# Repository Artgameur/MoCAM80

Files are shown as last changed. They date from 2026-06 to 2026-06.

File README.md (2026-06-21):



<p align="center">
  

  <a href="README.fr.md">
    
  </a>
</p>

# Table of Contents

* [Introduction](#Introduction)
* [Quick Description](#Quick-Description)
* [Firmware](#Firmware)
* [Architecture](#Architecture)
* [Features](#Features)
* [Images](#Images)
* [Components](#Components)
* [Instructions](#Instructions)
* [Schematic](#Schematic)
* [PCB](#PCB)

# Introduction

This is a project that I made for fun and to challenge myself during my second year of college as an electrical engineering student. Since I was working at 3dkeycap (a small-scale customizable keycap manufacturer), I thought about making a mechanical split keyboard. Since I was using a standard-size optical keyboard and my father is a programmer, I thought of making one for him too. This also happens to be my first GitHub repository.

Since I didn't know much about split keyboards, the thumb cluster ended up being a little unusual. Because I was making a keyboard for a programmer, it had to have a function row. At that point, I knew that the keyboard was going to be larger than standard layouts such as the Lily58 or Corne. Since it was already going to be that large, I thought, "Why not make it bigger?" So I ended up adding 80 keys.

So here is my finished project.

# Quick Description

MoCAM80 is a raspberry pi pico 2 powered 80 key split machanical keyboard. It has a reversible PCB design so that there is only one PCB version for both sides.

# Firmware

The keyboard uses custom firmware written specifically for the MoCAM80.

The left half acts as the primary controller while the right half operates as a secondary controller connected through TRRS via UART. Precompiled UF2 files are provided in the repository for both halves.

# Architecture

* Left PCB: main controller (USB HID)
* Right PCB: secondary matrix scanner
* Communication: UART via TRRS
* Firmware: custom C/C++

# Features

* A 6-key thumb cluster
* A number row
* A function row
* A 3D-printable case
* A reversible PCB (the same design is used for both sides)

# Images



















# Components

## PCB Assembly

### Required
| Quantity | Component |
|---|---|
| 80 | Choc V2 switches |
| 80 | MX low-profile keycaps |
| 2 | Raspberry Pi Pico 2 |
| 2 | TRRS (4-pole) female connectors |
| 1 | TRRS (4-pole) cable |
| 1 | Micro-USB data cable |

### Optional
| Quantity | Component |
|---|---|
| 12 | 10 kΩ resistors (internal pull-ups are enabled) |

## Case
| Material | Quantity |
|---|---|
| filament | 300g |

# Instructions

1. Once you have 2 PCBs, solder 1 Raspberry Pi Pico 2 onto each PCB.

2. Solder 1 female TRRS connector onto each PCB. (Be careful when handling them, as excessive force while plugging or unplugging the cable may lift pads from the PCB.)

3. Solder 40 switches onto one PCB and 40 switches onto the other PCB.

4. OPTIONAL: Solder 6 10 kΩ resistors onto each PCB.

5. On the left-hand PCB (the one with the switches on the same side as the Pico 2 and the TRRS connector), cut the upper two traces shown below, located near the bottom-right corner of the Pico 2.

<p align="center">

</p>

6. On the right-hand PCB (the one with the switches on the opposite side of the Pico 2 and the TRRS connector), cut the lower two traces shown below, located near the bottom-right corner of the Pico 2.

<p align="center">

</p>

7. Upload the [UF2 file for the main board](Software/Compiled%20Files/keyboard_Main.uf2) to the left-hand PCB.

8. Upload the [UF2 file for the secondary board](Software/Compiled%20Files/keyboard_Secondary.uf2) to the right-hand PCB.

9. Confirm that everything works correctly.

10. Print the case and assemble the final product.

# Schematic



# PCB
## Top Side



## Bottom Side



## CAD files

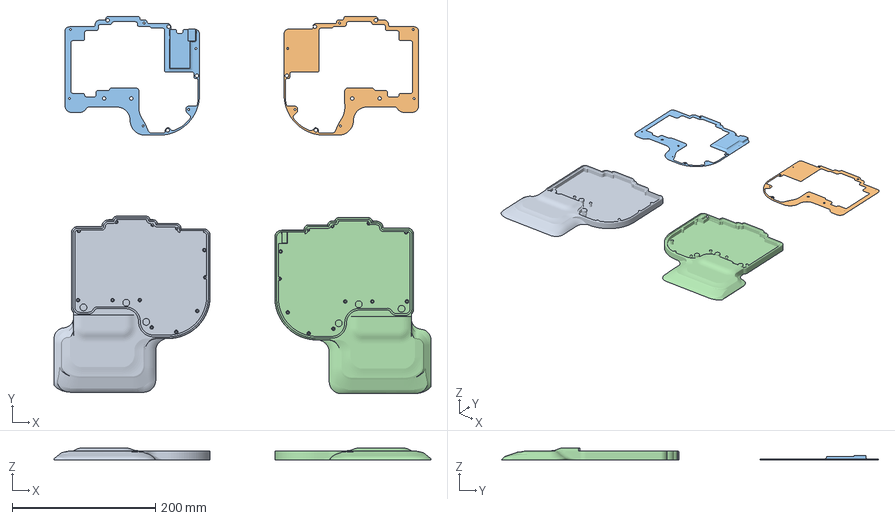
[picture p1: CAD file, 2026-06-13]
Hardware/Case/Keyboard-Case.3mf
526.5 x 527.2 x 17.0 mm

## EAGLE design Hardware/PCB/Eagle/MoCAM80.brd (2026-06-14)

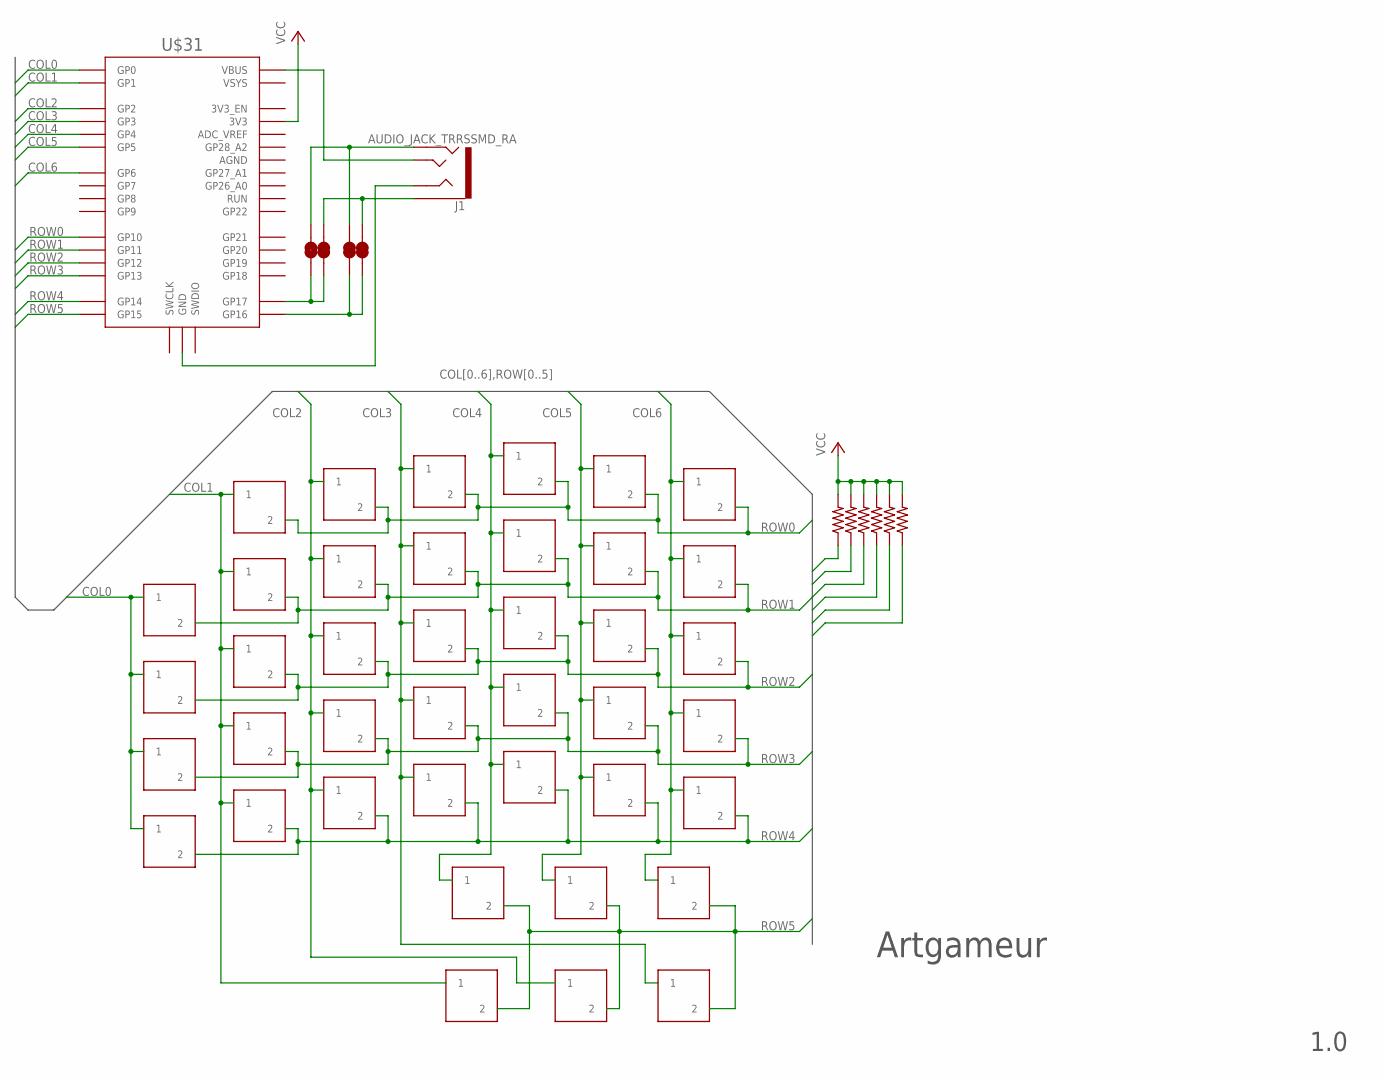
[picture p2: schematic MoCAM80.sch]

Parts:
J1: AUDIO_JACK_TRRSSMD_RA; AUDIO_JACK_3.5MM_TRRS_SMD_RA
JP1, JP2, JP3, JP4: JUMPER-SMT_2_NC_TRACE_NO-SILK; SMT-JUMPER_2_NC_TRACE_NO-SILK
R1, R2, R3, R4, R5, R6: R-US_CHIP-1206(3216-METRIC); RESC3216X70
U$1, U$2, U$3, U$4, U$5, U$6, U$7, U$8, U$9, U$10, U$11, U$12, U$13, U$14, U$15, U$16, U$17, U$18, U$19, U$21, U$22, U$23, U$24, U$26, U$27, U$28, U$29, U$32, U$33, U$34, U$35, U$36, U$37, U$38: KEYBOARD_SWITCHMX_CHOC_V2_SWAP; MX_CHOC_V2_SWAP
U$20, U$25: KEYBOARD_SWITCHMX_CHOC_V2_1.25; MX_CHOC_V2_1.25
U$30, U$39, U$40, U$41: KEYBOARD_SWITCHMX_CHOC_V2_1.5; MX_CHOC_V2_1.5
U$31: RPI_PICO-SMD; RPI_PICO

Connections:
COL0: U$1.P$1 (1), U$1.P$4 (1), U$2.P$1 (1), U$2.P$4 (1), U$3.P$1 (1), U$3.P$4 (1), U$31.GP0, U$38.P$1 (1), U$38.P$4 (1)
COL1: U$4.P$1 (1), U$4.P$4 (1), U$5.P$1 (1), U$5.P$4 (1), U$6.P$1 (1), U$6.P$4 (1), U$7.P$1 (1), U$7.P$4 (1), U$20.P$1 (1), U$20.P$4 (1), U$31.GP1, U$32.P$1 (1), U$32.P$4 (1)
COL2: U$8.P$1 (1), U$8.P$4 (1), U$9.P$1 (1), U$9.P$4 (1), U$10.P$1 (1), U$10.P$4 (1), U$11.P$1 (1), U$11.P$4 (1), U$25.P$1 (1), U$25.P$4 (1), U$31.GP2, U$33.P$1 (1), U$33.P$4 (1)
COL3: U$12.P$1 (1), U$12.P$4 (1), U$13.P$1 (1), U$13.P$4 (1), U$14.P$1 (1), U$14.P$4 (1), U$15.P$1 (1), U$15.P$4 (1), U$31.GP3, U$34.P$1 (1), U$34.P$4 (1), U$39.P$1 (1), U$39.P$4 (1)
COL4: U$16.P$1 (1), U$16.P$4 (1), U$17.P$1 (1), U$17.P$4 (1), U$18.P$1 (1), U$18.P$4 (1), U$19.P$1 (1), U$19.P$4 (1), U$30.P$1 (1), U$30.P$4 (1), U$31.GP4, U$35.P$1 (1), U$35.P$4 (1)
COL5: U$21.P$1 (1), U$21.P$4 (1), U$22.P$1 (1), U$22.P$4 (1), U$23.P$1 (1), U$23.P$4 (1), U$24.P$1 (1), U$24.P$4 (1), U$31.GP5, U$36.P$1 (1), U$36.P$4 (1), U$40.P$1 (1), U$40.P$4 (1)
COL6: U$26.P$1 (1), U$26.P$4 (1), U$27.P$1 (1), U$27.P$4 (1), U$28.P$1 (1), U$28.P$4 (1), U$29.P$1 (1), U$29.P$4 (1), U$31.GP6, U$37.P$1 (1), U$37.P$4 (1), U$41.P$1 (1), U$41.P$4 (1)
JACK_1: J1.TIP, U$31.VBUS
JACK_2: J1.RING2, JP2.2, JP4.2
JACK_GND: J1.RING1, U$31.GND@1 (GND), U$31.GND@2 (GND), U$31.GND@3 (GND), U$31.GND@4 (GND), U$31.GND@5 (GND), U$31.GND@6 (GND), U$31.GND@7 (GND), U$31.GND@8 (GND)
JACK_TIP: J1.EARTH, JP1.2, JP3.2
ROW0: R6.1, U$31.GP10, U$32.P$2 (2), U$33.P$2 (2), U$34.P$2 (2), U$35.P$2 (2), U$36.P$2 (2), U$37.P$2 (2)
ROW1: R1.1, U$4.P$2 (2), U$8.P$2 (2), U$12.P$2 (2), U$16.P$2 (2), U$21.P$2 (2), U$26.P$2 (2), U$31.GP11, U$38.P$2 (2)
ROW2: R2.1, U$1.P$2 (2), U$5.P$2 (2), U$9.P$2 (2), U$13.P$2 (2), U$17.P$2 (2), U$22.P$2 (2), U$27.P$2 (2), U$31.GP12
ROW3: R3.1, U$2.P$2 (2), U$6.P$2 (2), U$10.P$2 (2), U$14.P$2 (2), U$18.P$2 (2), U$23.P$2 (2), U$28.P$2 (2), U$31.GP13
ROW4: R4.1, U$3.P$2 (2), U$7.P$2 (2), U$11.P$2 (2), U$15.P$2 (2), U$19.P$2 (2), U$24.P$2 (2), U$29.P$2 (2), U$31.GP14
ROW5: R5.1, U$20.P$2 (2), U$25.P$2 (2), U$30.P$2 (2), U$31.GP15, U$39.P$2 (2), U$40.P$2 (2), U$41.P$2 (2)
UART_RX: JP1.1, JP4.1, U$31.GP17
UART_TX: JP2.1, JP3.1, U$31.GP16
VCC: R1.2, R2.2, R3.2, R4.2, R5.2, R6.2, U$31.3V3

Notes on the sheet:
Artgameur
1.0

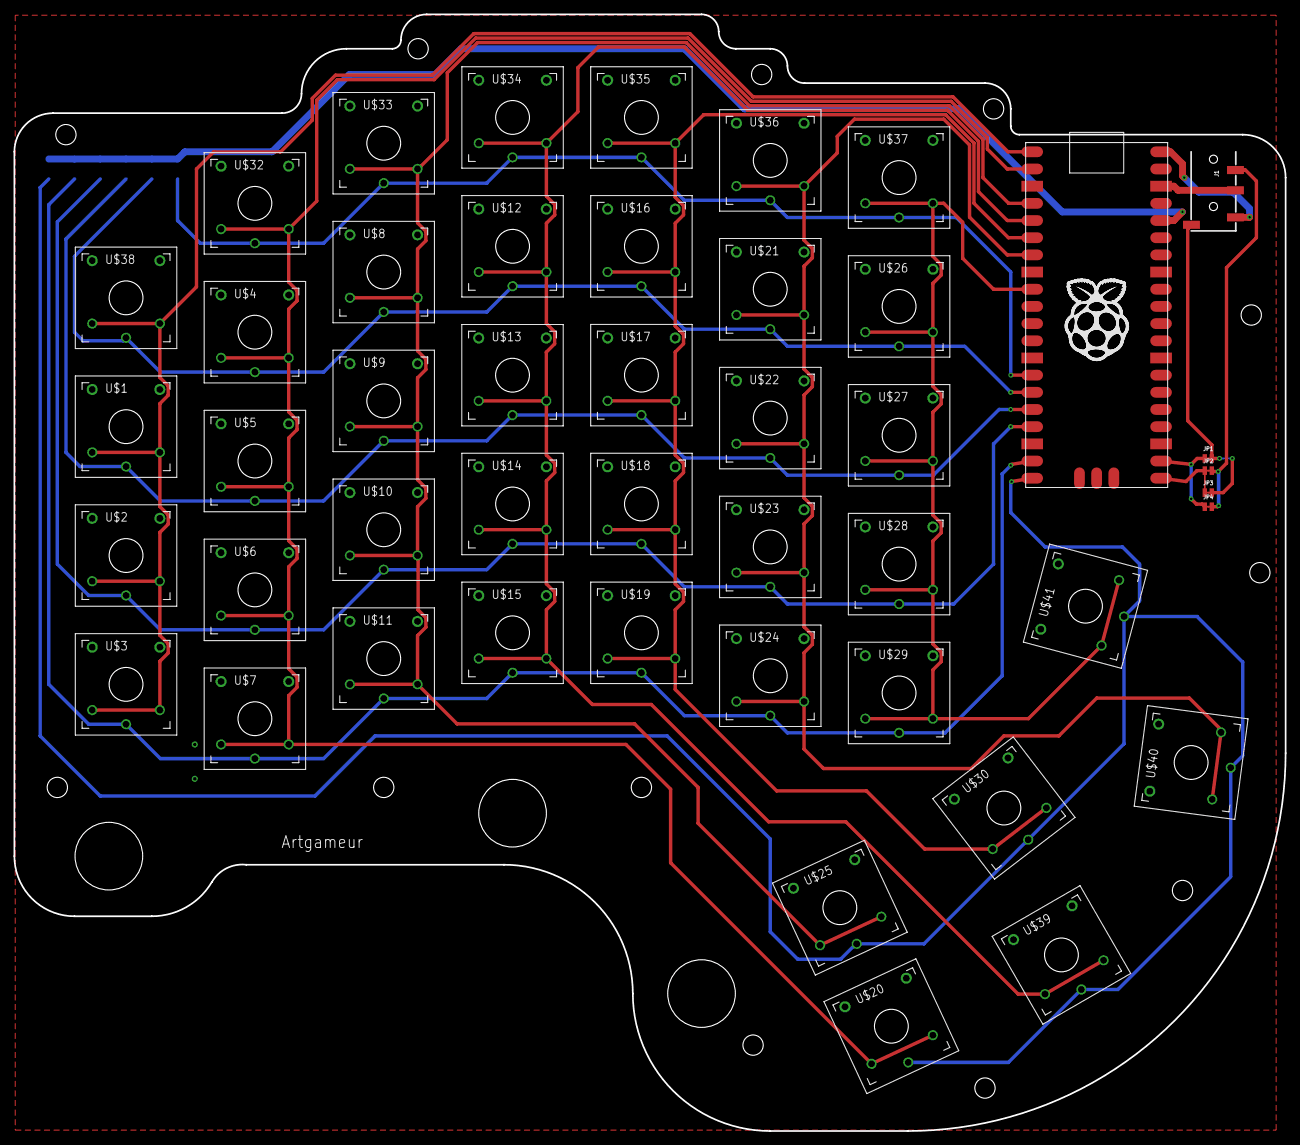
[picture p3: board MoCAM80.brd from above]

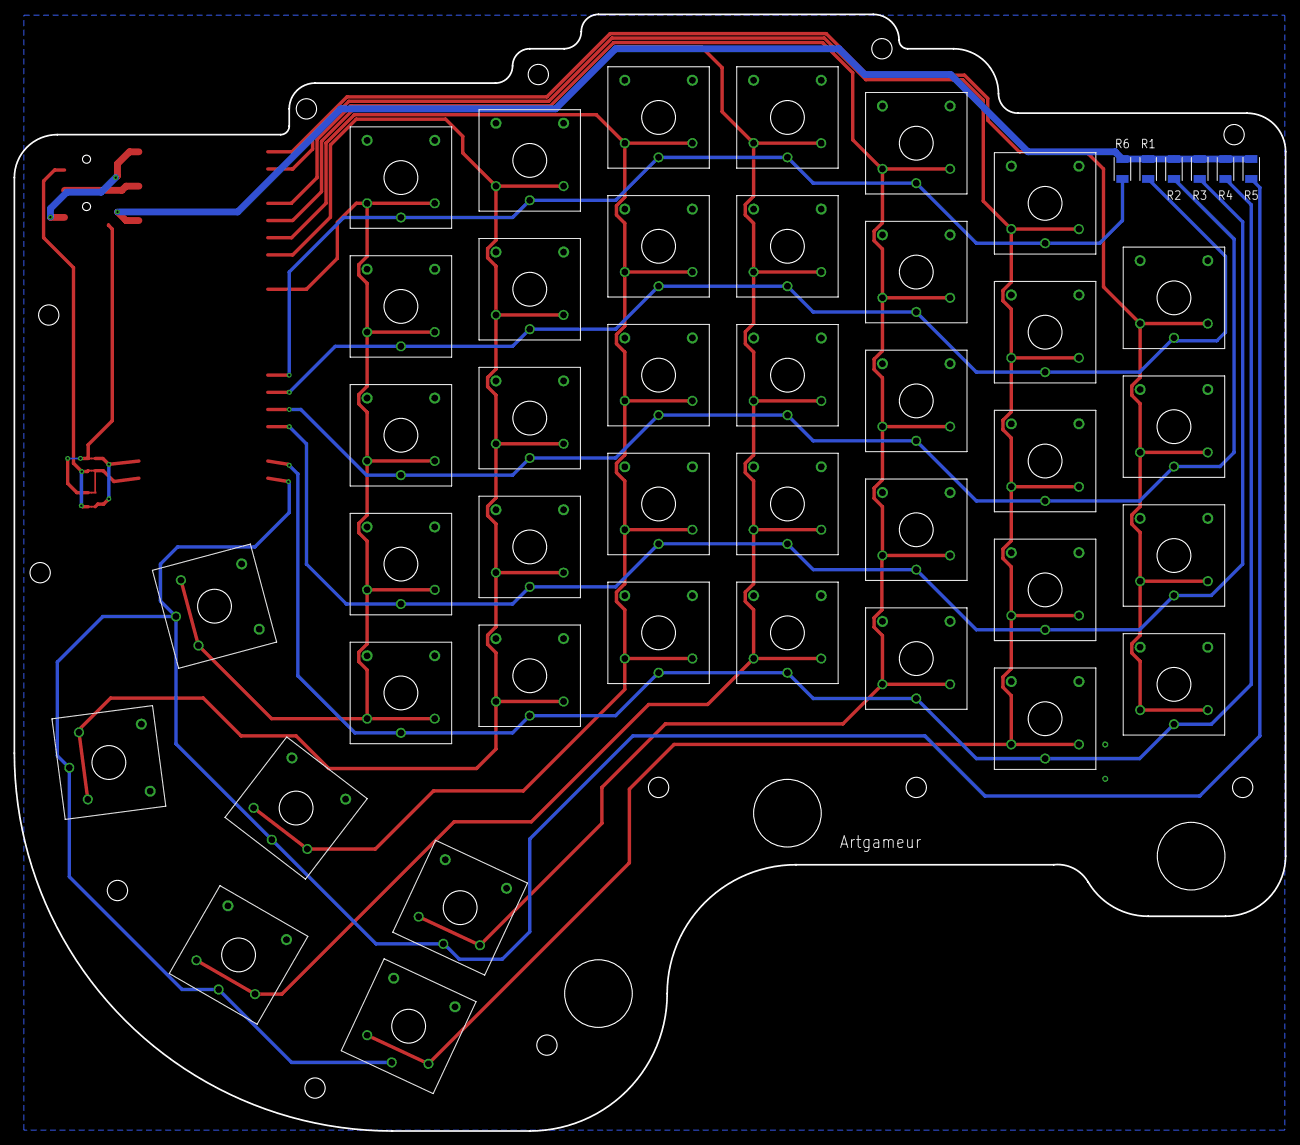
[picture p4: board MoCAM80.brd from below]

Board: 2 copper layers, 188.0 x 165.1 mm, 52 parts (6 on the bottom side), 20 nets.

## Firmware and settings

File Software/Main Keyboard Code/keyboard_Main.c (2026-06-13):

/*
 * Copyright (C) 2026  Artgameur
 *
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
 * You should have received a copy of the GNU General Public License
 * along with this program.  If not, see <https://www.gnu.org/licenses/>.
 */

/*
 * Split Keyboard – PRIMARY (left) half
 * =====================================
 * • Scans its own 6×7 key matrix  (GP10–GP15 rows, GP0–GP6 cols)
 * • Receives right half key states from the secondary over UART0
 *     RX = GP17  (secondary TX = GP16, cross-wired)
 * • Sends USB HID keyboard reports via TinyUSB
 */

#include <string.h>
#include "pico/stdlib.h"
#include "hardware/uart.h"
#include "bsp/board.h"
#include "tusb.h"

// ─── Pin / peripheral definitions ────────────────────────────────────────────

#define NUM_ROWS  6
#define NUM_COLS  7

static const uint ROW_PINS[NUM_ROWS] = {10, 11, 12, 13, 14, 15};
static const uint COL_PINS[NUM_COLS] = {0,  1,  2,  3,  4,  5,  6};

#define UART_INST    uart0
#define UART_RX_PIN  17
#define UART_BAUD    1000000

// ─── Packet protocol (secondary → primary) ───────────────────────────────────
// [0xAA][row0..row5][XOR_checksum][0x55]  = 9 bytes total
#define START_BYTE   0xAAu
#define END_BYTE     0x55u
#define PACKET_SIZE  (NUM_ROWS + 3)   // 9

// ─── HID Usage IDs ───────────────────────────────────────────────────────────
// Letters A–Z
#define HID_A  0x04u
#define HID_B  0x05u
#define HID_C  0x06u
#define HID_D  0x07u
#define HID_E  0x08u
#define HID_F  0x09u
#define HID_G  0x0Au
#define HID_H  0x0Bu
#define HID_I  0x0Cu
#define HID_J  0x0Du
#define HID_K  0x0Eu
#define HID_L  0x0Fu
#define HID_M  0x10u
#define HID_N  0x11u
#define HID_O  0x12u
#define HID_P  0x13u
#define HID_Q  0x14u
#define HID_R  0x15u
#define HID_S  0x16u
#define HID_T  0x17u
#define HID_U  0x18u
#define HID_V  0x19u
#define HID_W  0x1Au
#define HID_X  0x1Bu
#define HID_Y  0x1Cu
#define HID_Z  0x1Du
// Digits
#define HID_1  0x1Eu
#define HID_2  0x1Fu
#define HID_3  0x20u
#define HID_4  0x21u
#define HID_5  0x22u
#define HID_6  0x23u
#define HID_7  0x24u
#define HID_8  0x25u
#define HID_9  0x26u
#define HID_0  0x27u
// Control
#define HID_ENTER   0x28u
#define HID_ESC     0x29u
#define HID_BKSP    0x2Au
#define HID_TAB     0x2Bu
#define HID_SPACE   0x2Cu
// Punctuation
#define HID_MINUS   0x2Du
#define HID_EQUAL   0x2Eu
#define HID_LBRACKET 0x2Fu
#define HID_RBRACKET 0x30u
#define HID_BSLASH  0x31u
#define HID_SEMI    0x33u
#define HID_QUOTE   0x34u
#define HID_GRAVE   0x35u
#define HID_COMMA   0x36u
#define HID_DOT     0x37u
#define HID_SLASH   0x38u
#define HID_CAPS    0x39u
// Function keys
#define HID_F1  0x3Au
#define HID_F2  0x3Bu
#define HID_F3  0x3Cu
#define HID_F4  0x3Du
#define HID_F5  0x3Eu
#define HID_F6  0x3Fu
#define HID_F7  0x40u
#define HID_F8  0x41u
#define HID_F9  0x42u
#define HID_F10 0x43u
#define HID_F11 0x44u
#define HID_F12 0x45u
// Navigation
#define HID_DEL   0x4Cu
#define HID_RIGHT 0x4Fu
#define HID_LEFT  0x50u
#define HID_DOWN  0x51u
#define HID_UP    0x52u
// Modifiers (0xE0–0xE7) – handled separately in HID report modifier byte
#define HID_LCTRL  0xE0u
#define HID_LSHIFT 0xE1u
#define HID_LALT   0xE2u
#define HID_LGUI   0xE3u
#define HID_RCTRL  0xE4u
#define HID_RSHIFT 0xE5u
#define HID_RALT   0xE6u
// Sentinel – no key
#define HID_NONE   0x00u
// Media / Consumer Control (HID Usage Page 0x0C)
#define CONSUMER_PLAY_PAUSE   0x00CDu
#define CONSUMER_STOP         0x00B7u
#define CONSUMER_NEXT_TRACK   0x00B5u
#define CONSUMER_PREV_TRACK   0x00B6u
#define CONSUMER_FAST_FORWARD 0x00B3u
#define CONSUMER_REWIND       0x00B4u
#define CONSUMER_MUTE         0x00E2u
#define CONSUMER_VOL_UP       0x00E9u
#define CONSUMER_VOL_DOWN     0x00EAu

// ─── Keymaps ─────────────────────────────────────────────────────────────────
// Indexed [row][col].  Modifier keycodes (0xE0+) are extracted to the
// modifier byte; all others fill the 6-key slots.

static const uint8_t LEFT_KEYMAP[NUM_ROWS][NUM_COLS] = {
    // col: 0          1         2         3         4         5         6
    { HID_NONE,  HID_F1,   HID_F2,   HID_F3,   HID_F4,   HID_F5,        HID_F6   }, // row 0
    { HID_ESC,   HID_1,    HID_2,    HID_3,    HID_4,    HID_5,         HID_6    }, // row 1
    { HID_TAB,   HID_Q,    HID_W,    HID_E,    HID_R,    HID_T,         HID_GRAVE}, // row 2
    { HID_LSHIFT,HID_A,    HID_S,    HID_D,    HID_F,    HID_G,         HID_CAPS }, // row 3
    { HID_LCTRL, HID_Z,    HID_X,    HID_C,    HID_V,    HID_B,         HID_LALT }, // row 4
    { HID_NONE,  HID_LEFT, HID_SPACE,HID_DOWN, HID_UP,   HID_RIGHT,     HID_LGUI }, // row 5
};

static const uint8_t RIGHT_KEYMAP[NUM_ROWS][NUM_COLS] = {
    // col: 0          1         2         3         4         5         6
    { HID_NONE,  HID_F12,  HID_F11,  HID_F10,  HID_F9,   HID_F8,   HID_F7   }, // row 0
    { HID_BKSP,  HID_EQUAL,HID_MINUS,HID_0,    HID_9,    HID_8,    HID_7    }, // row 1
    { HID_ENTER, HID_P,    HID_O,    HID_I,    HID_U,    HID_Y,    HID_QUOTE}, // row 2
    { HID_RSHIFT,HID_BSLASH,HID_L,   HID_K,    HID_J,    HID_H,    HID_SEMI }, // row 3
    { HID_RCTRL, HID_DOT,  HID_COMMA,HID_M,    HID_N,    HID_B,    HID_SLASH}, // row 4
    { HID_NONE,  HID_RALT, HID_SPACE, HID_RBRACKET,HID_LBRACKET,HID_DEL, CONSUMER_PLAY_PAUSE}, // row 5
};

// ─── Debounce state ───────────────────────────────────────────────────────────
#define DEBOUNCE_CYCLES 20   // 20 × 500 µs = 10 ms – sufficient for mechanical switches
#define STARTUP_IGNORE_SCANS 200

static int8_t  raw_count[NUM_ROWS][NUM_COLS];
static bool    debounced[NUM_ROWS][NUM_COLS];
static bool    startup_reports_enabled = false;
static uint16_t startup_ignore_scans = 0;

// ─── Right-half state (from UART) ────────────────────────────────────────────
static bool right_state[NUM_ROWS][NUM_COLS];

// ─── UART RX ring buffer ──────────────────────────────────────────────────────
#define RX_BUF_SIZE 128

static uint8_t rx_buf[RX_BUF_SIZE];
static uint    rx_head = 0;   // write index
static uint    rx_tail = 0;   // read  index

static inline uint rx_len(void)  { return (rx_head - rx_tail) & (RX_BUF_SIZE - 1); }
static inline bool rx_empty(void){ return rx_head == rx_tail; }

static void uart_drain(void) {
    while (uart_is_readable(UART_INST) && rx_len() < RX_BUF_SIZE - 1) {
        rx_buf[rx_head & (RX_BUF_SIZE - 1)] = (uint8_t)uart_getc(UART_INST);
        rx_head++;
    }
}

static uint8_t rx_peek(uint offset) {
    return rx_buf[(rx_tail + offset) & (RX_BUF_SIZE - 1)];
}

static void rx_consume(uint n) {
    rx_tail += n;
}

// ─── Hardware initialisation ──────────────────────────────────────────────────

static void gpio_init_matrix(void) {
    // Columns: outputs, idle-high.
    // Set the output register HIGH *before* switching to output mode so
    // the pin never briefly glitches LOW and falsely asserts all rows.
    for (uint c = 0; c < NUM_COLS; c++) {
        gpio_init(COL_PINS[c]);
        gpio_put(COL_PINS[c], 1);
        gpio_set_dir(COL_PINS[c], GPIO_OUT);
    }
    // Rows: inputs. External 2 kΩ pull-ups hold the line HIGH; a keypress
    // shorts the row to the driven-LOW column.
    // Internal pull-ups (~50 kΩ) are also enabled so that a missing or
    // broken external pull-up cannot leave a row pin floating LOW and
    // cause phantom keypresses for every key in that row.
    for (uint r = 0; r < NUM_ROWS; r++) {
        gpio_init(ROW_PINS[r]);
        gpio_set_dir(ROW_PINS[r], GPIO_IN);
        gpio_pull_up(ROW_PINS[r]);
    }
}

static void uart_init_secondary(void) {
    uart_init(UART_INST, UART_BAUD);
    // Pull RX high before muxing to UART so the line idles correctly
    // even when the secondary half is not yet connected.
    gpio_pull_up(UART_RX_PIN);
    gpio_set_function(UART_RX_PIN, GPIO_FUNC_UART);
    uart_set_hw_flow(UART_INST, false, false);
    uart_set_format(UART_INST, 8, 1, UART_PARITY_NONE);
}

// ─── Matrix scan & debounce ───────────────────────────────────────────────────

static void scan_and_debounce(void) {
    for (uint c = 0; c < NUM_COLS; c++) {
        gpio_put(COL_PINS[c], 0);
        sleep_us(5);
        for (uint r = 0; r < NUM_ROWS; r++) {
            bool pressed = !gpio_get(ROW_PINS[r]);
            if (pressed) {
                if (raw_count[r][c] < DEBOUNCE_CYCLES)
                    raw_count[r][c]++;
                if (raw_count[r][c] == DEBOUNCE_CYCLES)
                    debounced[r][c] = true;
            } else {
                if (raw_count[r][c] > 0)
                    raw_count[r][c]--;
                if (raw_count[r][c] == 0)
                    debounced[r][c] = false;
            }
        }
        gpio_put(COL_PINS[c], 1);
    }
}

// ─── UART packet parser ───────────────────────────────────────────────────────

static void parse_uart(void) {
    uart_drain();

    while (rx_len() >= PACKET_SIZE) {
        // Find START_BYTE
        if (rx_peek(0) != START_BYTE) {
            rx_consume(1);
            continue;
        }
        // Check END_BYTE
        if (rx_peek(PACKET_SIZE - 1) != END_BYTE) {
            rx_consume(1);   // bad frame; skip
            continue;
        }
        // Verify XOR checksum over the NUM_ROWS row bytes (offsets 1..6)
        uint8_t chk = 0;
        for (uint r = 0; r < NUM_ROWS; r++)
            chk ^= rx_peek(1 + r);
        if (chk == rx_peek(1 + NUM_ROWS)) {
            for (uint r = 0; r < NUM_ROWS; r++) {
                uint8_t row_byte = rx_peek(1 + r);
                for (uint c = 0; c < NUM_COLS; c++)
                    right_state[r][c] = (row_byte >> c) & 1u;
            }
        }
        rx_consume(PACKET_SIZE);
    }
}

// ─── HID report builder ──────────────────────────────────────────────────────

// Returns the modifier-byte bit for a modifier keycode, or 0 if not a modifier.
static inline uint8_t modifier_bit(uint8_t hid) {
    if (hid >= 0xE0u && hid <= 0xE7u)
        return (uint8_t)(1u << (hid - 0xE0u));
    return 0;
}

static void build_keyboard_report(uint8_t *modifier, uint8_t keycodes[6]) {
    *modifier = 0;
    memset(keycodes, 0, 6);

    uint key_count = 0;

    for (uint r = 0; r < NUM_ROWS; r++) {
        for (uint c = 0; c < NUM_COLS; c++) {
            uint8_t hid = HID_NONE;

            if (debounced[r][c])
                hid = LEFT_KEYMAP[r][c];
            else if (right_state[r][c])
                hid = RIGHT_KEYMAP[r][c];

            if (hid == HID_NONE) continue;

            uint8_t mod = modifier_bit(hid);
            if (mod) {
                *modifier |= mod;
            } else if (key_count < 6) {
                keycodes[key_count++] = hid;
            }
        }
    }
}

static void send_hid_report(void) {
    if (!tud_hid_ready()) return;

    uint8_t modifier;
    uint8_t keycodes[6];

    build_keyboard_report(&modifier, keycodes);
    tud_hid_keyboard_report(0, modifier, keycodes);
}

// ─── TinyUSB callbacks ────────────────────────────────────────────────────────

// Invoked when USB is mounted (host has enumerated the device).
// Reset all debounce state so any pre-enumeration transients are discarded
// and the first report sent to the host reflects only live key state.
void tud_mount_cb(void) {
    memset(raw_count,   0, sizeof(raw_count));
    memset(debounced,   0, sizeof(debounced));
    memset(right_state, 0, sizeof(right_state));
    startup_reports_enabled = false;
    startup_ignore_scans = 0;
}

// Invoked when GET_REPORT control request is received.
uint16_t tud_hid_get_report_cb(uint8_t instance, uint8_t report_id,
                                hid_report_type_t report_type,
                                uint8_t *buffer, uint16_t reqlen) {
    (void)instance; (void)report_id;

    if (report_type != HID_REPORT_TYPE_INPUT || reqlen == 0)
        return 0;

    uint8_t modifier;
    uint8_t keycodes[6];
    uint8_t report[8] = {0};
    uint16_t report_len = reqlen < sizeof(report) ? reqlen : sizeof(report);

    if (startup_reports_enabled) {
        build_keyboard_report(&modifier, keycodes);
        report[0] = modifier;
        memcpy(&report[2], keycodes, sizeof(keycodes));
    }

    memcpy(buffer, report, report_len);
    return report_len;
}

// Invoked when SET_REPORT or data is received on OUT endpoint.
void tud_hid_set_report_cb(uint8_t instance, uint8_t report_id,
                            hid_report_type_t report_type,
                            const uint8_t *buffer, uint16_t bufsize) {
    (void)instance; (void)report_id; (void)report_type;
    (void)buffer; (void)bufsize;
}

// ─── Main ─────────────────────────────────────────────────────────────────────

int main(void) {
    board_init();
    tusb_init();

    gpio_init_matrix();
    uart_init_secondary();

    memset(raw_count,   0, sizeof(raw_count));
    memset(debounced,   0, sizeof(debounced));
    memset(right_state, 0, sizeof(right_state));
    startup_reports_enabled = false;
    startup_ignore_scans = 0;

    // Previous HID state – used to detect changes
    uint8_t prev_modifier    = 0;
    uint8_t prev_keycodes[6] = {0};

    while (true) {
        tud_task();          // TinyUSB device task

        scan_and_debounce();
        parse_uart();

        // Build new report
        uint8_t modifier;
        uint8_t keycodes[6];

        build_keyboard_report(&modifier, keycodes);

        if (!startup_reports_enabled) {
            if (startup_ignore_scans < STARTUP_IGNORE_SCANS) {
                startup_ignore_scans++;
            } else {
                memset(raw_count,   0, sizeof(raw_count));
                memset(debounced,   0, sizeof(debounced));
                memset(right_state, 0, sizeof(right_state));
                startup_reports_enabled = true;
                prev_modifier = 0;
                memset(prev_keycodes, 0, sizeof(prev_keycodes));
                continue;
            }
        }

        // Send report only when state changes
        if (startup_reports_enabled && tud_hid_ready()) {
            if (modifier != prev_modifier ||
                memcmp(keycodes, prev_keycodes, 6) != 0)
            {
                tud_hid_keyboard_report(0, modifier, keycodes);
                prev_modifier = modifier;
                memcpy(prev_keycodes, keycodes, 6);
            }
        }

        sleep_us(500);   // ~500 µs scan interval
    }
}

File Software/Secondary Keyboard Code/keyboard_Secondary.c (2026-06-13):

/*
 * Copyright (C) 2026  Artgameur
 *
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
 * You should have received a copy of the GNU General Public License
 * along with this program.  If not, see <https://www.gnu.org/licenses/>.
 */

#include <stdbool.h>
#include <stdint.h>

#include "hardware/gpio.h"
#include "hardware/uart.h"
#include "pico/stdlib.h"

#define NUM_ROWS 6
#define NUM_COLS 7
#define UART_ID uart0
#define UART_TX_PIN 16
#define UART_RX_PIN 17
#define UART_BAUD_RATE 1000000
#define START_BYTE 0xAA
#define END_BYTE 0x55
#define DEBOUNCE_CYCLES 5
#define PACKET_SIZE (NUM_ROWS + 3)

static const uint8_t row_pins[NUM_ROWS] = {10, 11, 12, 13, 14, 15};
static const uint8_t col_pins[NUM_COLS] = {0, 1, 2, 3, 4, 5, 6};

static uint8_t raw_count[NUM_ROWS][NUM_COLS];
static bool debounced[NUM_ROWS][NUM_COLS];

static void matrix_init(void) {
    for (uint8_t col = 0; col < NUM_COLS; ++col) {
        gpio_init(col_pins[col]);
        gpio_put(col_pins[col], true);
        gpio_set_dir(col_pins[col], GPIO_OUT);
    }

    for (uint8_t row = 0; row < NUM_ROWS; ++row) {
        gpio_init(row_pins[row]);
        gpio_set_dir(row_pins[row], GPIO_IN);
        gpio_disable_pulls(row_pins[row]);
    }
}

static void uart_setup(void) {
    uart_init(UART_ID, UART_BAUD_RATE);
    gpio_set_function(UART_TX_PIN, GPIO_FUNC_UART);
    gpio_set_function(UART_RX_PIN, GPIO_FUNC_UART);
    uart_set_format(UART_ID, 8, 1, UART_PARITY_NONE);
    uart_set_hw_flow(UART_ID, false, false);
    uart_set_fifo_enabled(UART_ID, true);
}

static void scan_raw(bool state[NUM_ROWS][NUM_COLS]) {
    for (uint8_t col = 0; col < NUM_COLS; ++col) {
        gpio_put(col_pins[col], false);
        sleep_us(5);

        for (uint8_t row = 0; row < NUM_ROWS; ++row) {
            state[row][col] = !gpio_get(row_pins[row]);
        }

        gpio_put(col_pins[col], true);
    }
}

static bool debounce_matrix(const bool raw[NUM_ROWS][NUM_COLS]) {
    bool changed = false;

    for (uint8_t row = 0; row < NUM_ROWS; ++row) {
        for (uint8_t col = 0; col < NUM_COLS; ++col) {
            if (raw[row][col]) {
                if (raw_count[row][col] < DEBOUNCE_CYCLES) {
                    ++raw_count[row][col];
                }
                if (raw_count[row][col] == DEBOUNCE_CYCLES && !debounced[row][col]) {
                    debounced[row][col] = true;
                    changed = true;
                }
            } else {
                if (raw_count[row][col] > 0) {
                    --raw_count[row][col];
                }
                if (raw_count[row][col] == 0 && debounced[row][col]) {
                    debounced[row][col] = false;
                    changed = true;
                }
            }
        }
    }

    return changed;
}

static void build_packet(uint8_t packet[PACKET_SIZE]) {
    uint8_t checksum = 0;

    packet[0] = START_BYTE;
    for (uint8_t row = 0; row < NUM_ROWS; ++row) {
        uint8_t row_bits = 0;
        for (uint8_t col = 0; col < NUM_COLS; ++col) {
            if (debounced[row][col]) {
                row_bits |= (uint8_t)(1u << col);
            }
        }
        packet[row + 1] = row_bits;
        checksum ^= row_bits;
    }
    packet[NUM_ROWS + 1] = checksum;
    packet[NUM_ROWS + 2] = END_BYTE;
}

int main(void) {
    bool last_packet_valid = false;
    uint8_t packet[PACKET_SIZE] = {0};
    bool raw_state[NUM_ROWS][NUM_COLS] = {{false}};

    matrix_init();
    uart_setup();

    while (true) {
        scan_raw(raw_state);

        if (debounce_matrix(raw_state) || !last_packet_valid) {
            build_packet(packet);
            uart_write_blocking(UART_ID, packet, PACKET_SIZE);
            last_packet_valid = true;
        }

        sleep_ms(1);
    }
}

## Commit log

2026-06-13 Fix formatting in assembly instructions
    Removed an empty line in the assembly instructions.
2026-06-13 Add Schematic and PCB sections to README
    Added sections for Schematic and PCB with images.
2026-06-13 Update PCB images in README
    Replaced images for the top and bottom sides of the PCB.
2026-06-14 Add French README translation for MoCAM80 project
    Added French translation of the README file, including project details, specifications, and assembly instructions for the MoCAM80 mechanical keyboard.
2026-06-14 Update language switch images in README.fr.md

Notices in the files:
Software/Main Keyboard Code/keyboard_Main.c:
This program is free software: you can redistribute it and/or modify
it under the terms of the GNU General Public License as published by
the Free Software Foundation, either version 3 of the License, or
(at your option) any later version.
